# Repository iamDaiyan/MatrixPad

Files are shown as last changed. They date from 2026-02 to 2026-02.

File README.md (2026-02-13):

# MatrixPad
A 9 Key Programmable Macropad with Encoder & OLED Display<br><br>
MatrixPad is a fully programmable 9-key macropad designed for productivity, content creation, coding, and everyday shortcuts. Built around the **Seeed XIAO RP2040**, it features 9 Mechanical keys, a clean 3D-printed enclosure, rotary encoder input, and OLED display support.
## Features
* 9 Mechanical Keys (3x3 grid layout)
* Rotary Encoder 
* 0.91 inch OLED Display 
* Powered by Seeed XIAO RP2040 (Through-Hole)
* 2-Layer PCB (≤100mm x 100mm)
* Fully 3D Printed Case
* Programmable Firmware (KMK / QMK compatible)

---

## Overall Hackpad
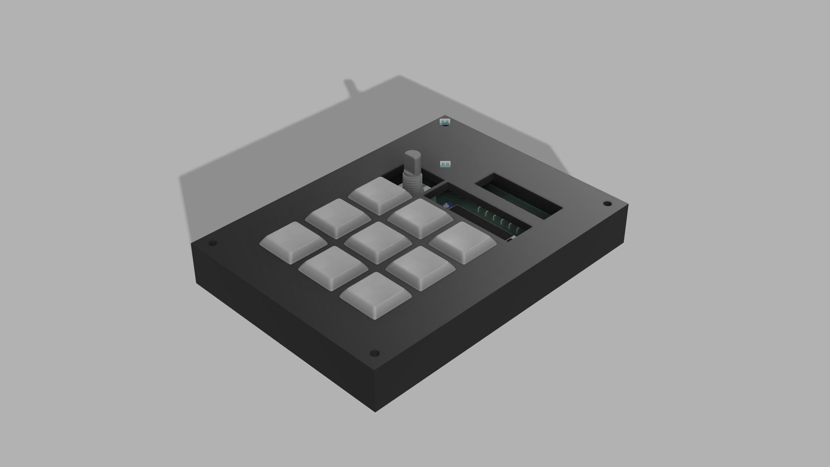
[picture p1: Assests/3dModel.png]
Overall Hackpad


## Schematic
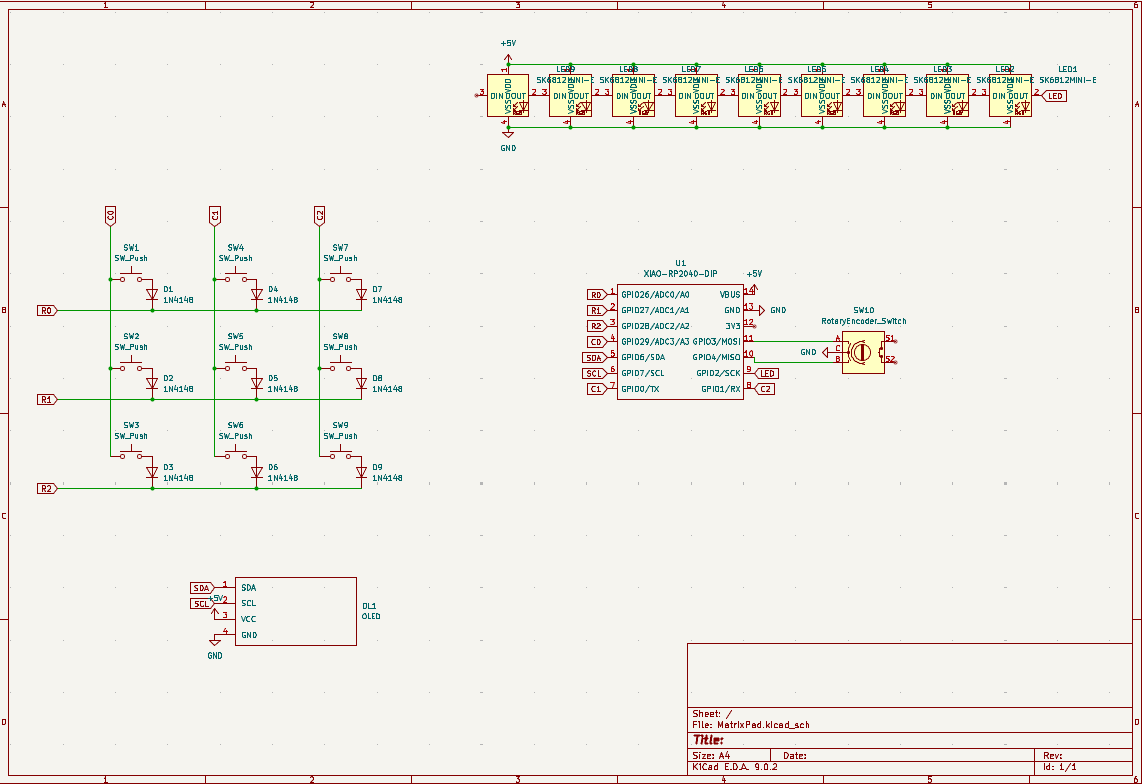
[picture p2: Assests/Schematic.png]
Schematic


## PCB
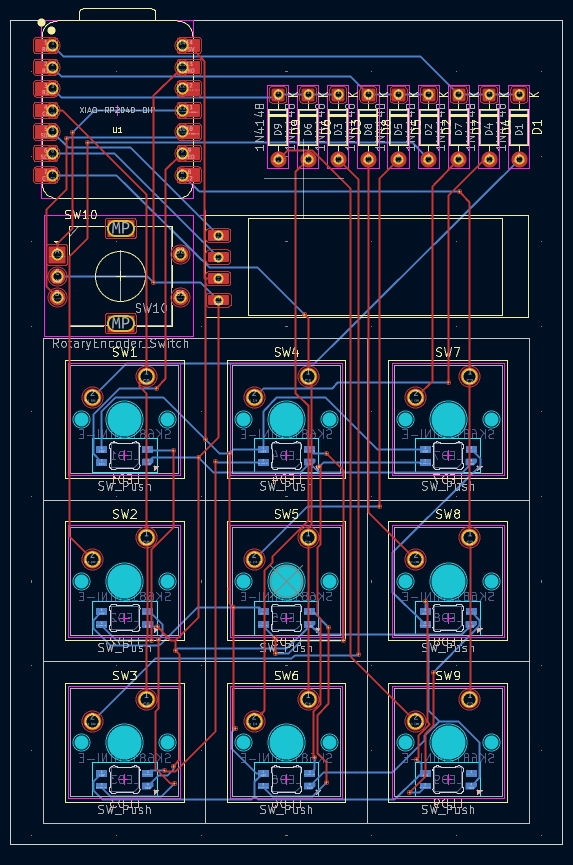
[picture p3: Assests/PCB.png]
PCB


## Case Design
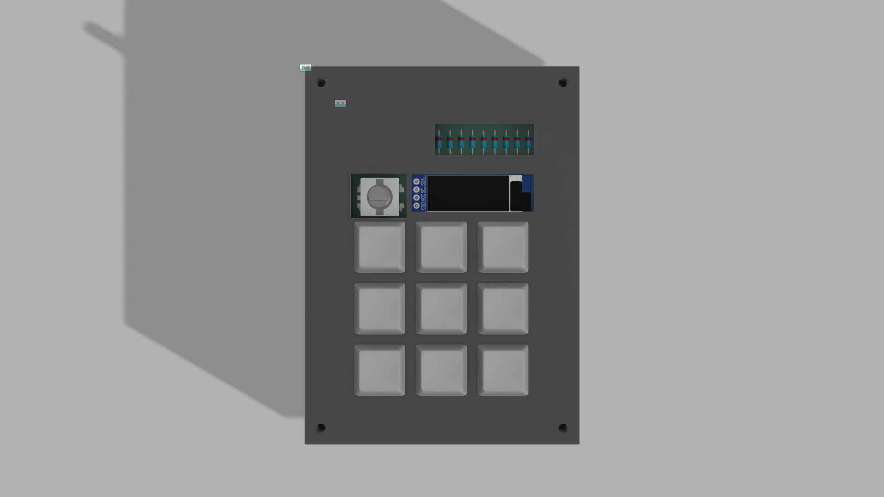
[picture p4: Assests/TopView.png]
Case CAD


---

## BOM

| Item | Quantity |
|---|---|
| Seeed XIAO RP2040 (Through-Hole) | 1 |
| MX-Style Mechanical Switches  | 9 |
| Through-hole 1N4148 Diodes | 9 |
| Blank DSA Keycaps (1u) | 9 |
| SK6812 MINI-E LEDs | 9 |
| EC11 Rotary Encoder | 1 |
| 0.91” OLED (I2C) | 1 |
| M3×16 mm Screws | 4 |
| M3×5 mm Heatset Inserts | 4 |
| PCB (2-Layer) | 1 |
| 3D Printed Case | 1 |

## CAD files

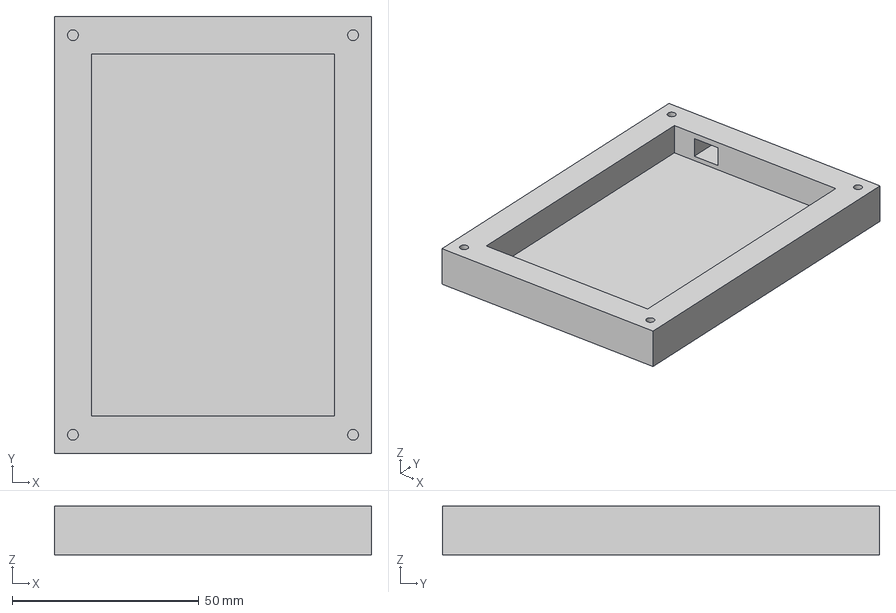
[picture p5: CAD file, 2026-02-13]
Production/Base.step
85.0 x 117.0 x 13.0 mm

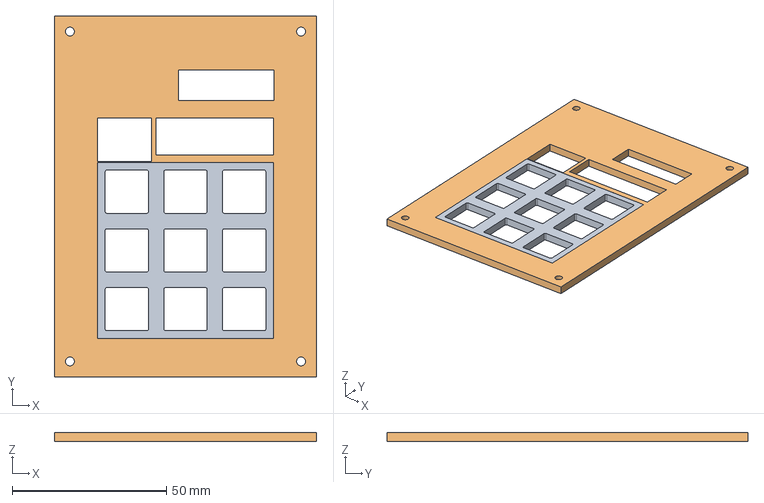
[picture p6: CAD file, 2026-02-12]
Production/Top.step
85.0 x 117.0 x 3.00 mm

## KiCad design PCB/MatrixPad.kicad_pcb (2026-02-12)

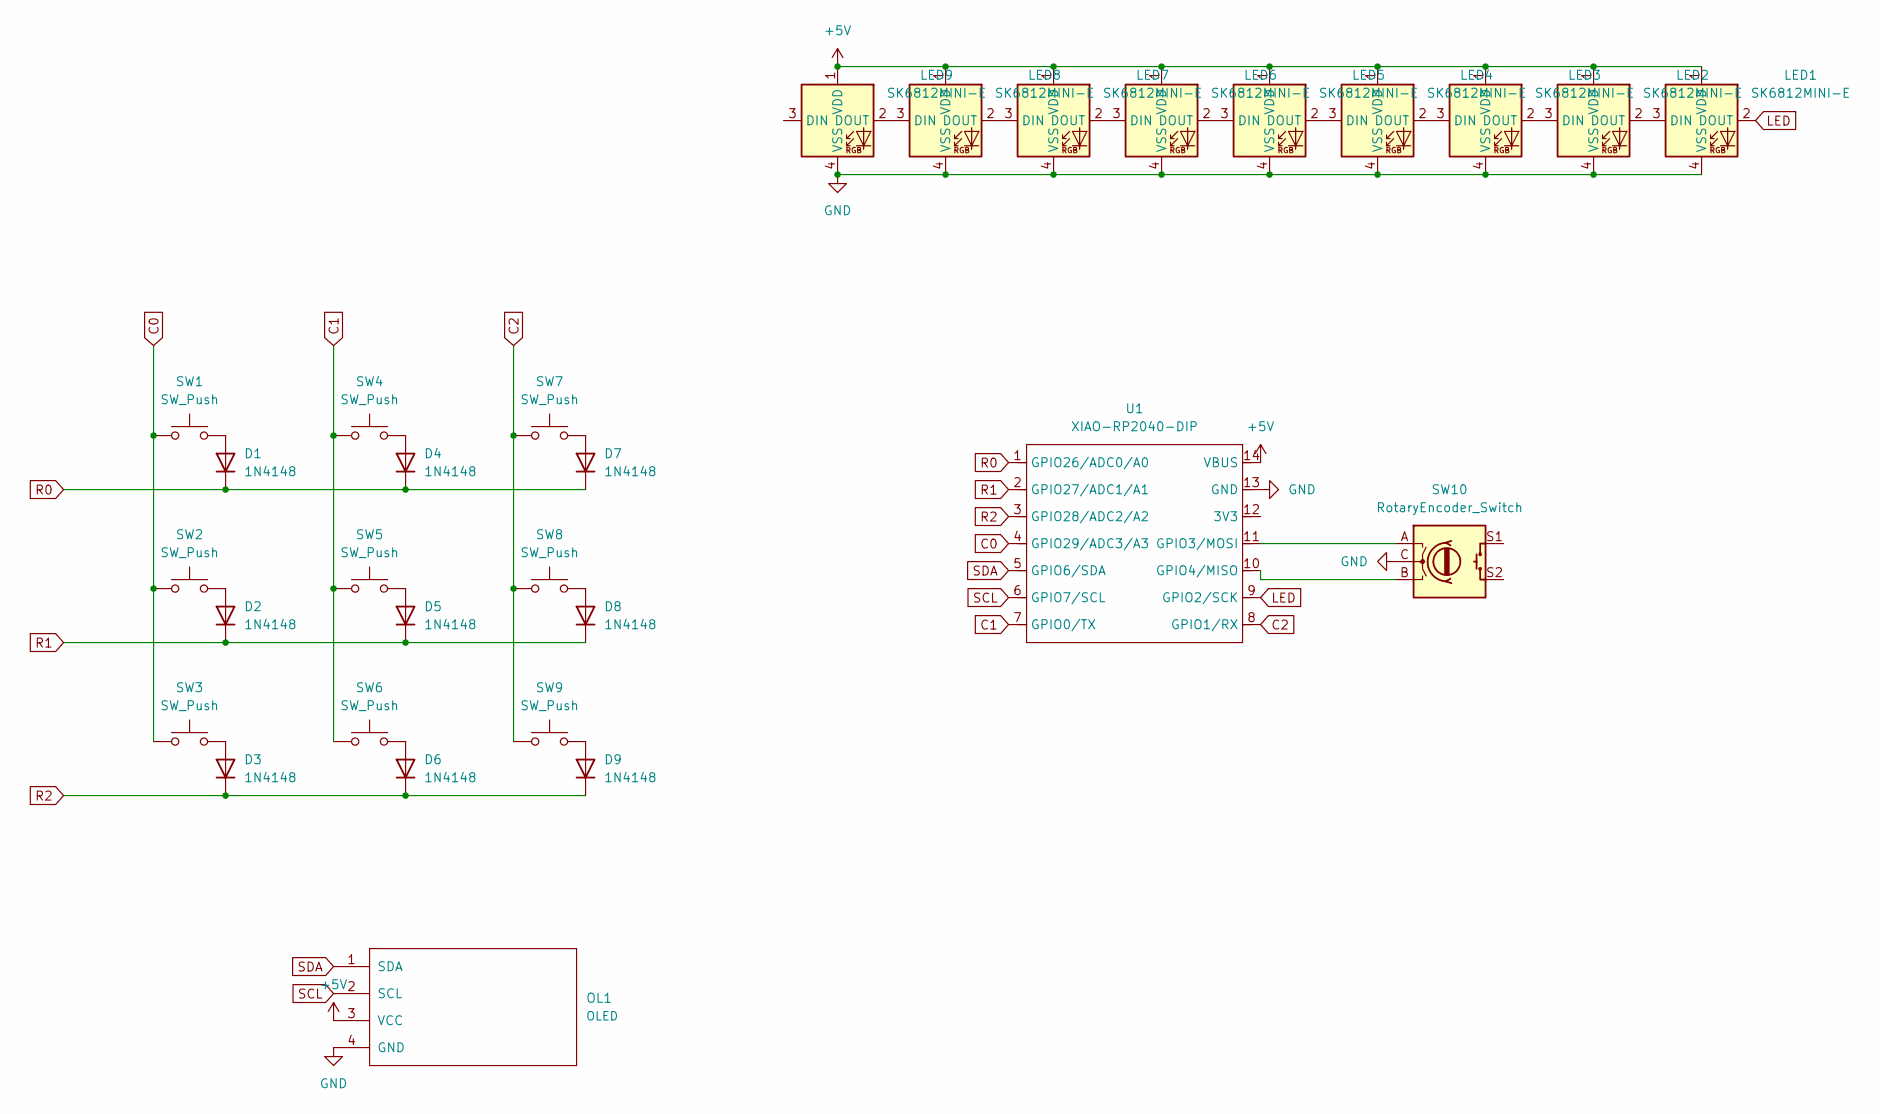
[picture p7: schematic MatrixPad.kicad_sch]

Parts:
D1, D2, D3, D4, D5, D6, D7, D8, D9: 1N4148; D_DO-35_SOD27_P7.62mm_Horizontal
LED1, LED2, LED3, LED4, LED5, LED6, LED7, LED8, LED9: SK6812MINI-E; LED_6028R
OL1: OLED; Adafruit_SSD1306
SW1, SW2, SW3, SW4, SW5, SW6, SW7, SW8, SW9: SW_Push; SW_Cherry_MX_1.00u_PCB
SW10: RotaryEncoder_Switch; RotaryEncoder_Alps_EC11E-Switch_Vertical_H20mm
U1: XIAO-RP2040-DIP

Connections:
+5V: LED1.1 (VDD), LED2.1 (VDD), LED3.1 (VDD), LED4.1 (VDD), LED5.1 (VDD), LED6.1 (VDD), LED7.1 (VDD), LED8.1 (VDD), LED9.1 (VDD), OL1.3 (VCC), U1.14 (VBUS)
C0: SW1.1, SW2.1, SW3.1, U1.4 (GPIO29/ADC3/A3)
C1: SW4.1, SW5.1, SW6.1, U1.7 (GPIO0/TX)
C2: SW7.1, SW8.1, SW9.1, U1.8 (GPIO1/RX)
GND: LED1.4 (VSS), LED2.4 (VSS), LED3.4 (VSS), LED4.4 (VSS), LED5.4 (VSS), LED6.4 (VSS), LED7.4 (VSS), LED8.4 (VSS), LED9.4 (VSS), OL1.4 (GND), SW10.C, U1.13 (GND)
LED: LED1.2 (DOUT), U1.9 (GPIO2/SCK)
unnamed: D1.2 (A), SW1.2
unnamed: D2.2 (A), SW2.2
unnamed: D3.2 (A), SW3.2
unnamed: D4.2 (A), SW4.2
unnamed: D5.2 (A), SW5.2
unnamed: D6.2 (A), SW6.2
unnamed: D7.2 (A), SW7.2
unnamed: D8.2 (A), SW8.2
unnamed: D9.2 (A), SW9.2
unnamed: LED1.3 (DIN), LED2.2 (DOUT)
unnamed: LED2.3 (DIN), LED3.2 (DOUT)
unnamed: LED3.3 (DIN), LED4.2 (DOUT)
unnamed: LED4.3 (DIN), LED5.2 (DOUT)
unnamed: LED5.3 (DIN), LED6.2 (DOUT)
unnamed: LED6.3 (DIN), LED7.2 (DOUT)
unnamed: LED7.3 (DIN), LED8.2 (DOUT)
unnamed: LED8.3 (DIN), LED9.2 (DOUT)
unnamed: SW10.A, U1.11 (GPIO3/MOSI)
unnamed: SW10.B, U1.10 (GPIO4/MISO)
R0: D1.1 (K), D4.1 (K), D7.1 (K), U1.1 (GPIO26/ADC0/A0)
R1: D2.1 (K), D5.1 (K), D8.1 (K), U1.2 (GPIO27/ADC1/A1)
R2: D3.1 (K), D6.1 (K), D9.1 (K), U1.3 (GPIO28/ADC2/A2)
SCL: OL1.2 (SCL), U1.6 (GPIO7/SCL)
SDA: OL1.1 (SDA), U1.5 (GPIO6/SDA)

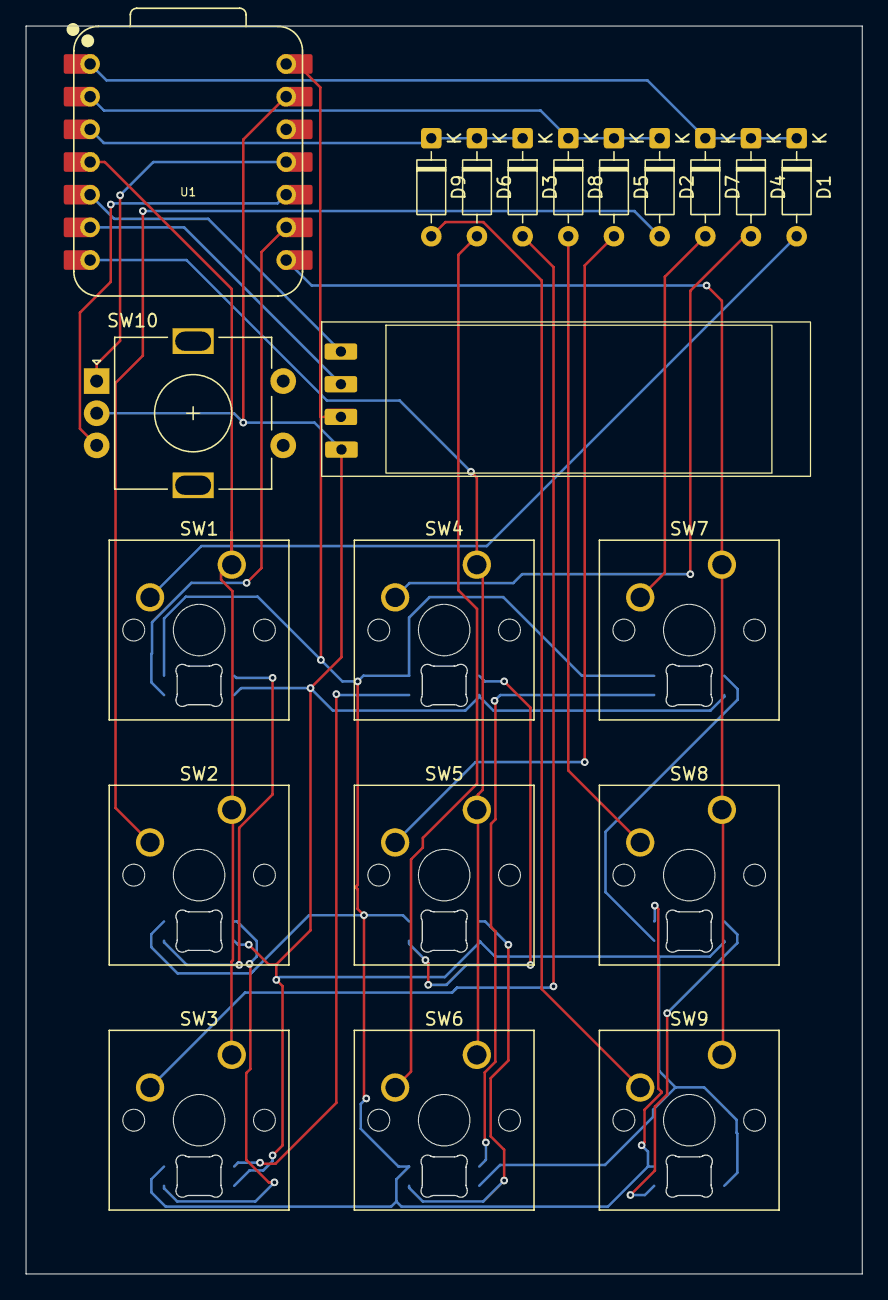
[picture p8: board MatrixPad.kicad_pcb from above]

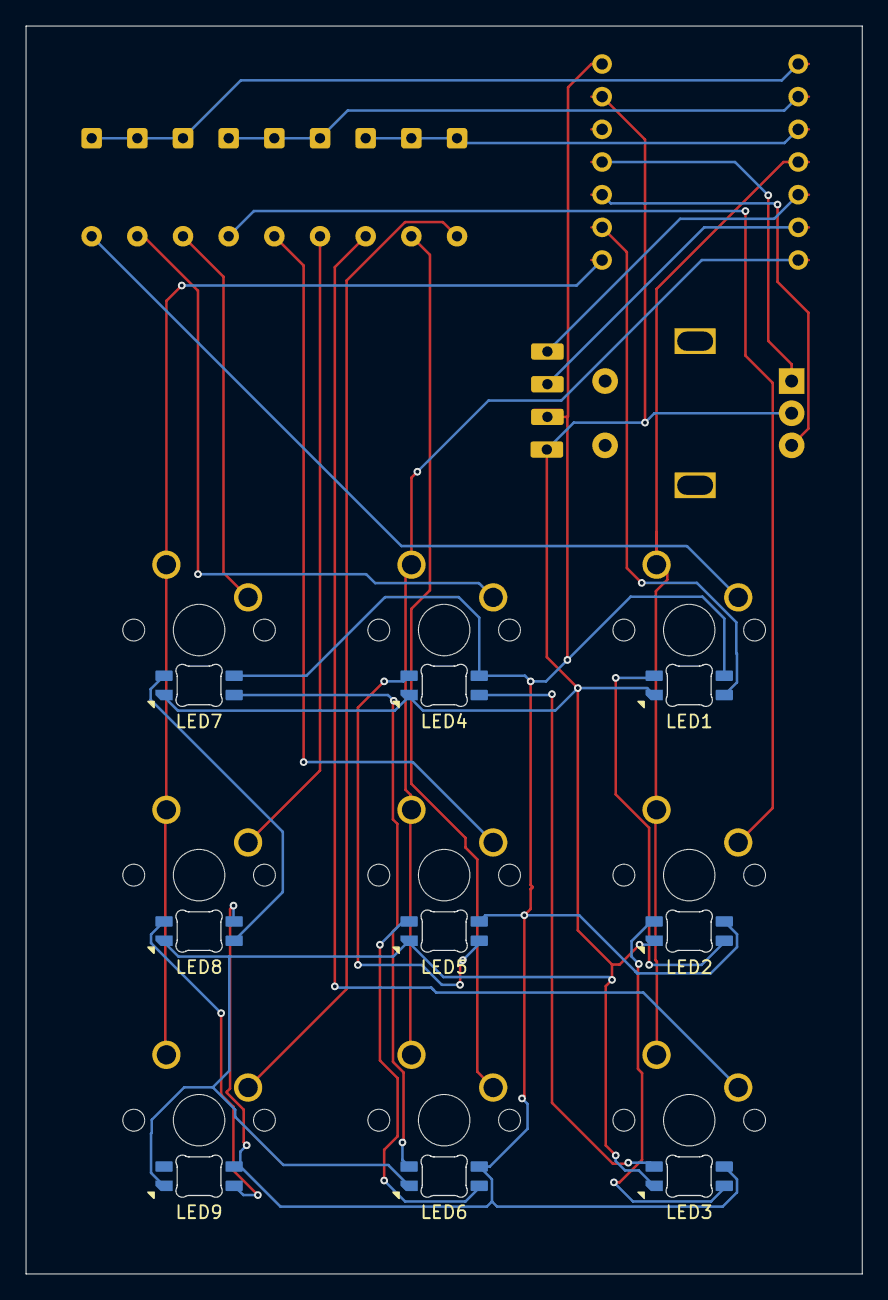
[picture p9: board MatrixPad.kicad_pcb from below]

Board: 2 copper layers, 65.0 x 97.0 mm, 30 parts (9 on the bottom side), 30 nets.

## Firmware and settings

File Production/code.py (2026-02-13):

print("Starting")

# Import
import board
import busio

# KMK Core
from kmk.kmk_keyboard import KMKKeyboard
from kmk.keys import KC
from kmk.scanners import DiodeOrientation

# RGB LEDs
from kmk.extensions.rgb import RGB

# Rotary Encoder
from kmk.modules.encoder import EncoderHandler, Encoder

# OLED Display
from kmk.extensions.oled import OLED, TextEntry

keyboard = KMKKeyboard()

# Matrix Configuration
keyboard.col_pins = (board.GP29, board.GP0, board.GP1)
keyboard.row_pins = (board.GP26, board.GP27, board.GP28)
keyboard.diode_orientation = DiodeOrientation.COL2ROW

# OLED Display Setup

i2c = busio.I2C(scl=board.GP7, sda=board.GP6)

oled = OLED(
    i2c=i2c,
    width=128,
    height=32,
    entries=[
        TextEntry(text="Keep Going!", x=0, y=0),
        TextEntry(text="Never Settle", x=0, y=16),
    ]
)

keyboard.extensions.append(oled)

# RGB LED Setup
rgb = RGB(
    pixel_pin=board.GP2,
    num_pixels=9,
)

keyboard.extensions.append(rgb)

# Rotary Encoder Setup
encoder_handler = EncoderHandler()

encoder_handler.encoders = (
    Encoder(
        pin_a=board.GP3,
        pin_b=board.GP4,
    ),
)

# Mapping Encoder rotation to Volume Up / Down
encoder_handler.map = [
    ((KC.VOLU, KC.VOLD),),  # (Clockwise, Counter-Clockwise)
]

keyboard.modules.append(encoder_handler)

# Keymap Configuration
keyboard.keymap = [
    [
        KC.N7, KC.N8, KC.N9,
        KC.N4, KC.N5, KC.N6,
        KC.N1, KC.N2, KC.N3,
    ]
]

# Run Keyboard
if __name__ == '__main__':
    keyboard.go()

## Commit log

2026-02-12 Added MatrixPad project files
    [Base.step, MatrixPad.kicad_pcb, MatrixPad.kicad_sch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]
2026-02-12 Added some more project files
    [MatrixPad.kicad_pcb]
2026-02-13 Added images, firmware, and updated Gerber files
2026-02-13 Added the USB-C cutout
    [Base.step]
